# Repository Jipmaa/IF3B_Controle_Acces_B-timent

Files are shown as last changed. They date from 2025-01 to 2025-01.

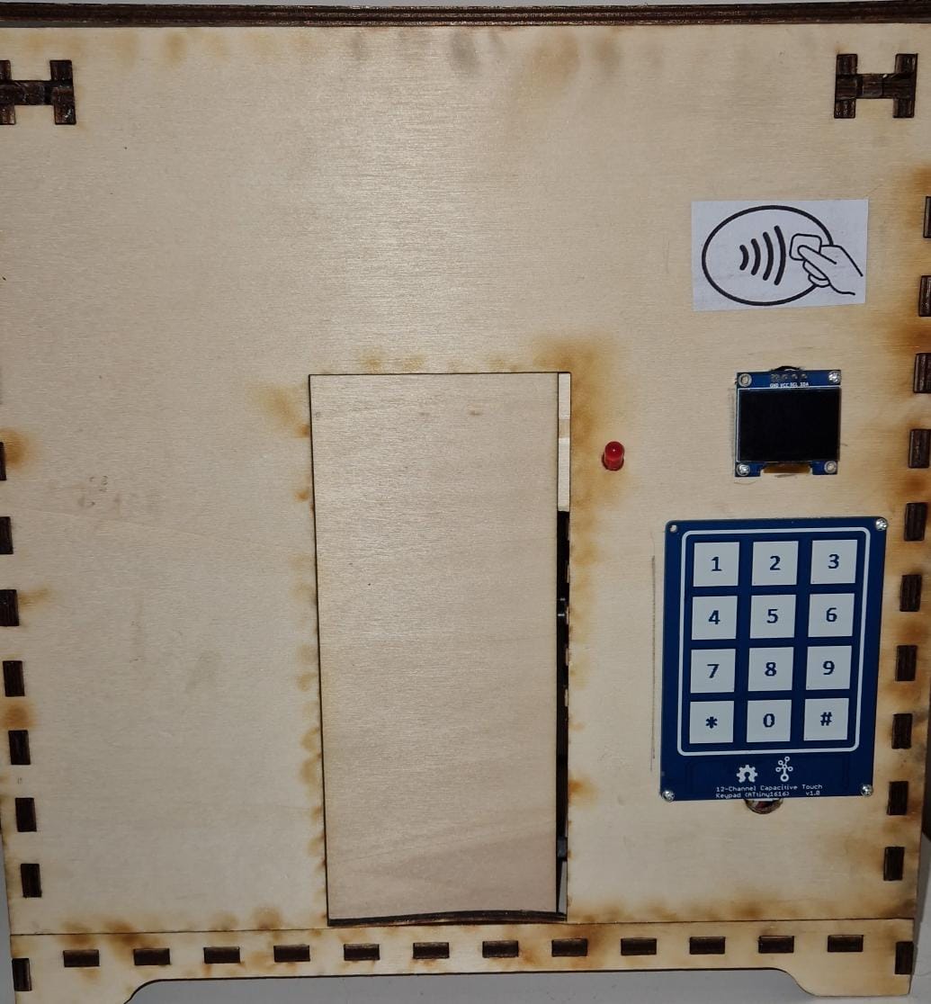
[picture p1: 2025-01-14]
Rendu/Rendu Maquette Face.jpg

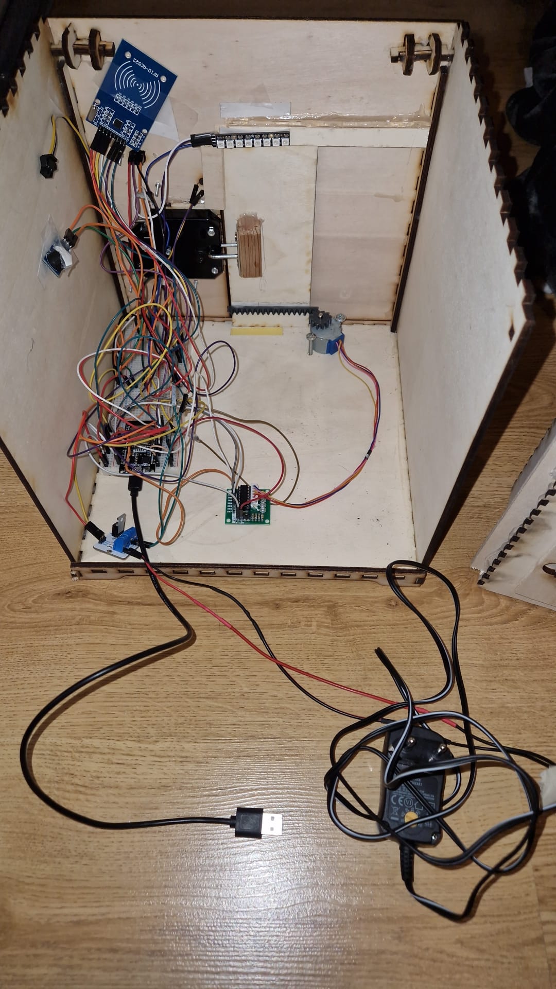
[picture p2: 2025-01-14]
Rendu/Rendu Maquette Interieur Cablage.jpg

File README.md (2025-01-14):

# Projet IF3B
## Contrôle d'accès à un bâtiment

### Contexte :
Dans le cadre des bâtiments modernes, le **contrôle d'accès** représente un enjeu crucial en matière de sécurité, d'efficacité et de gestion des flux de personnes. Les solutions classiques, souvent basées sur des serrures mécaniques ou des systèmes peu intelligents, présentent des limitations : faible flexibilité, difficulté d'intégration avec des systèmes domotiques, et absence de suivi en temps réel.
Pour répondre à ces défis, **notre projet vise à concevoir une solution innovante et interactive de contrôle d'accès pour un bâtiment quelconque**. L'objectif est de développer un système fonctionnel et modulable, intégrant la **communication bidirectionnelle** via Node-RED

### Identification des problèmes :
- Comment faire une porte qui permet d’être verrouillé et qui peut s’ouvrir à distance ?
- Comment indiquer de manière sécurisé qu’une porte va s’ouvrir / se fermer ?
- Comment faire un accès sécurisé et à la fois polyvalent ?
- Comment tracer les entrées des employées par exemple ?

### Solutions proposées :
- Système d’ouverture / fermeture avec porte coulissante modulable via nodered
- Utilisation d’un afficheur OLED, d’un voyant sonore et visuel pour la fermeture et prévenir également avant la fermeture
- Utiliser à la fois un lecteur de badge (module RFID) et un pavé tactile permettant une solution polyvalente
- Permettre l’utilisation d’un badge spécifique ou bien lié un code aux badges quelconques pour déterminer l’entrée d’un employé.

### Répartition des tâches : 
- Conception hardware
- Câblage
- Conception software (capteurs, actionneurs, communication MQTT via wifi)
- Mise en place du serveur NodeRed

### Capteurs / Actionneurs :
- __Module RFID :__ Pour permettre à quiconque possédant un badge valide de rentrer
- __Pavé tactile (keypad) :__ Pour permettre à quiconque possédant le code de rentrer
- __Buzzer :__ Pour indiquer par un bruit toute action fais par l’utilisateur ou bien par le mécanisme susceptible d’être un danger
- __Afficheur OLED :__ Pour indiquer visuellement les instructions à faire ou bien énoncé les erreurs
- __LedStick 8 leds neopixel :__ Pour éclairé l’intérieur, modulable très facilement
- __Moteur stepper :__ moteur pas à pas pour pouvoir faire des rotations sur 360° et ainsi permettre l’utilisation d’un rail et d’un pignon pour ouvrir la porte
- __Serrure à solénoïde :__ serrure permettant d’ouvrir facilement la porte, se ferme en se réenclenchant.

**__Autres :__**
- Résistance
- Led rouge
- Alimentation 12V pour serrure à solénoïde
- Relais pour serrure
- Transformateur pour stepper
- ESP32
- Breadboard

### Détails des pins
**RFID** :
- RST : D4 (modulable)
- MISO : D19
- MOSI : D23
- SCK : D18
- SDA : D5

**Moteur stepper** :
- int1 : D14 (modulable)
- int2 : D27 (modulable)
- int3 : D26 (modulable)
- int4 : D25 (modulable)

**Keypad** :
- RX : RX2
- TX : TX2

**Serrure à solénoïde** :
- SIG : D32 (modulable)

**Afficheur OLED** :
- SCL : D22
- SDA : D21

**LedStick 8 leds neopixel** :
- DIN : D33 (modulable)

**Buzzer** :
- I/O : D13 (modulable)

**Led rouge** :
- D13 (modulable)

**VCC / GND** :
Tous les pins VCC (pour le courant) et GND (pour la masse), sont à brancher sur une breadboard

**__Attention :__** La led ne pourra pas fonctionner correctement, tous les pins jugés "safe" sur l'esp32 sont utilisés, la led s'allumera donc à chaque impulsion électrique envoyé pour faire fonctionner le buzzer

### Câblage
Cablage
(seul la serrure est manquante)

### Rendu final photo
https://github.com/Jipmaa/IF3B_Controle_Acces_Batiment/tree/e7f2aa74cef77e2d99e59e1e05c4c83b59b73495/Rendu

### Rendu final vidéo
Vidéo présentation (https://mega.nz/embed/Z2RXjYpS#6Jan2xSJXGcZ-fgepvT3v_E5NKe26LIGEAMiwmIppC8)

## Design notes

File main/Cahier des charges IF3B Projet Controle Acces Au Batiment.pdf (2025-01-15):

Fabien THUNEVIN – Thomas BALMES – Malak ADAOU – Skander TRABELSI

# Cahier des charges IF3B Projet numéro 5 : Contrôle accès au bâtiment

## Table des matières

## 1. Contexte :

Dans le cadre des bâtiments modernes, le contrôle d'accès représente un enjeu crucial en matière de sécurité, d'efficacité et de gestion des flux de personnes. Les solutions classiques, souvent basées sur des serrures mécaniques ou des systèmes peu intelligents, présentent des limitations : faible flexibilité, difficulté d'intégration avec des systèmes domotiques, et absence de suivi en temps réel.

Pour répondre à ces défis, notre projet vise à concevoir une solution innovante et interactive de contrôle d'accès pour un bâtiment quelconque. L'objectif est de développer un système fonctionnel et modulable, intégrant la communication bidirectionnelle via Node-RED. Durant ce projet nous concevrons une maquette à la découpeuse laser ainsi qu’à l’imprimante 3D pour toute pièce rajoutée, et nous y intégrerons le matériel ARDUINO nécessaire au bon fonctionnement du projet.

## 2. Identification des problèmes

- Comment faire une porte qui permet d’être verrouillé et qui peut s’ouvrir à distance ?
- Comment indiquer de manière sécurisé qu’une porte va s’ouvrir / se fermer ?
- Comment faire un accès sécurisé et à la fois polyvalent ?
- Comment tracer les entrées des employées par exemple ?

## 3. Solutions proposées

- Système d’ouverture / fermeture avec porte coulissante modulable via nodered
- Utilisation d’un afficheur OLED, d’un voyant sonore et visuel pour la fermeture et prévenir également avant la fermeture
- Utiliser à la fois un lecteur de badge (module RFID) et un pavé tactile permettant une solution polyvalente

- Permettre l’utilisation d’un badge spécifique ou bien lié un code aux badges quelconques pour déterminer l’entrée d’un employé.

## 4. Répartition des tâches :

- Conception hardware : Malak ADAOU
- Câblage : Thomas BALMES
- Conception software (capteurs, actionneurs, communication MQTT via wifi) : Fabien THUNEVIN
- Mise en place du serveur NodeRed : Fabien THUNEVIN

La maquette va se présenter de la forme suivante : une maison avec une porte qui sera verrouillé par une serrure reliée à un contrôleur NFC qui s’active / désactive, un servomoteur ouvrira la porte et une led ainsi qu’un panneau OLED nous indiquera si la porte est ouverte ou non. Un détecteur fera en sorte que la porte ne se referme pas de manière abrupte sur une personne essayant de rentrer.

## 5. Capteurs / Actionneurs

- Module RFID : Pour permettre à quiconque possédant un badge valide de rentrer
- Pavé tactile : Pour permettre à quiconque possédant le code de rentrer
- Buzzer : Pour indiquer par un bruit toute action fais par l’utilisateur ou bien par le mécanisme susceptible d’être un danger
- Afficheur OLED : Pour indiquer visuellement les instructions à faire ou bien énoncé les erreurs
- LedStick 8 leds neopixel : Pour éclairer l’intérieur, modulable très facilement
- Moteur stepper : moteur pas à pas pour pouvoir faire des rotations sur 360° et ainsi permettre l’utilisation d’un rail et d’un pignon pour ouvrir la porte
- Serrure à solénoïde : serrure permettant d’ouvrir facilement la porte, se ferme en se réenclenchant.

Autres :

- 1 Led
- 1 Résistance
- 2 breadboards
- Câbles duponts
- 1 Câble micro-usb
- Microcontrôleur esp32
- Transformateur pour moteur stepper
- Relais pour serrure
- Alimentation 12V pour serrure à solenoïde.

## 6. Logigramme

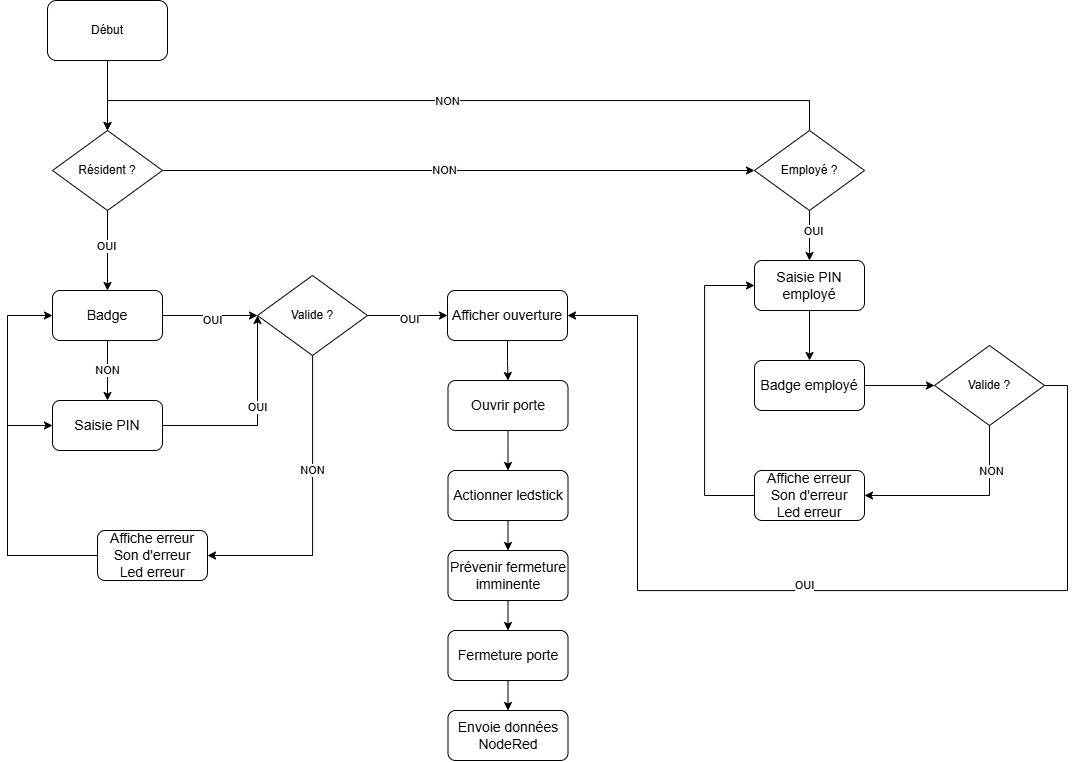
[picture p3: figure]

## 7. Schéma de câblage

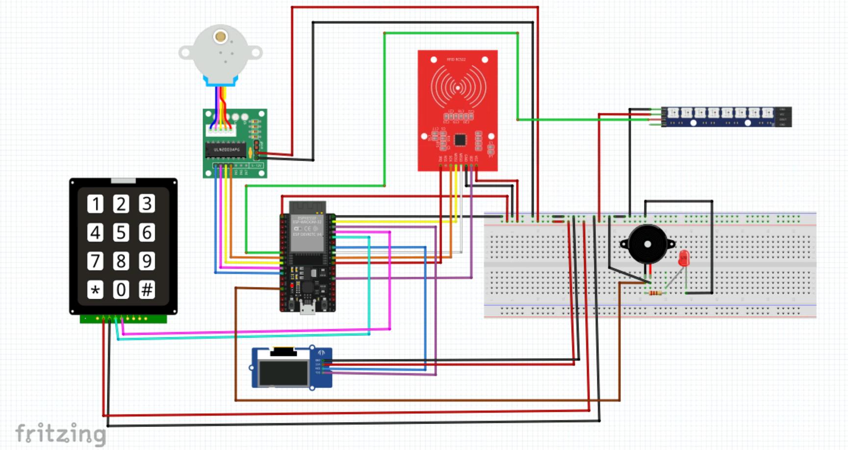
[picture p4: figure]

Ainsi qu’une serrure à solénoïde dont le SIG est branché sur le pin D32.

## 8. Intégration NodeRed

- Permet le contrôle de la porte et de ses 4 états (ouvert, ouverture, fermée, fermeture)
- Permet de contrôler les couleurs du LedStick
- Permet d’afficher le message de son choix sur l’écran OLED avec la taille souhaité tout en le faisant défilé. Également la possibilité de revenir au message initial
- Permet de donner une impulsion au buzzer pour émettre un son de la fréquence et à la durée souhaité

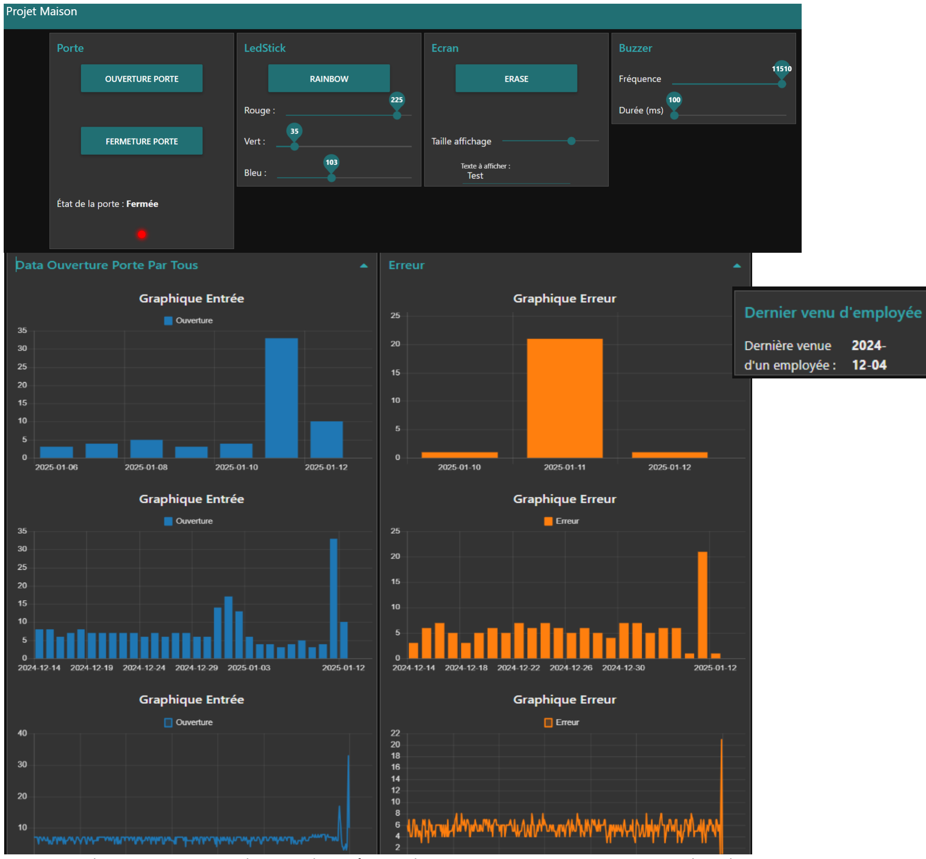
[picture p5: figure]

- Affichage des graphiques d’entrée et d’erreur sur les 7, 30 et 365 derniers jours

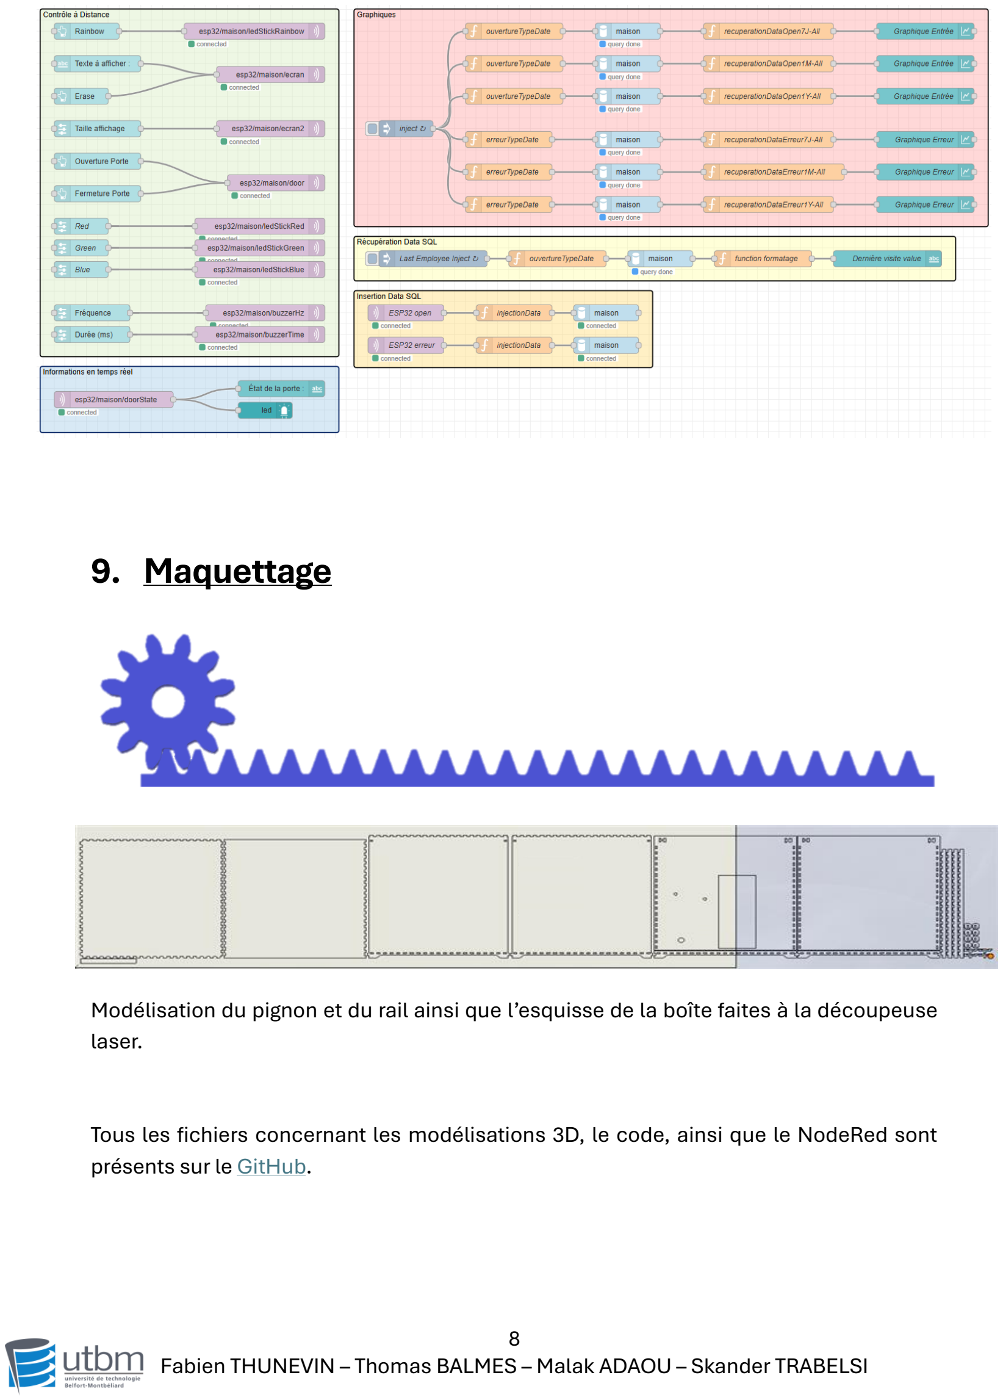
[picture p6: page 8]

## 9. Maquettage

Modélisation du pignon et du rail ainsi que l’esquisse de la boîte faites à la découpeuse laser.

Tous les fichiers concernant les modélisations 3D, le code, ainsi que le NodeRed sont présents sur le GitHub. (https://github.com/Jipmaa/IF3B_Controle_Acces_Batiment/tree/main)

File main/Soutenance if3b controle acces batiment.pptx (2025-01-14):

## Soutenance IF3B

Contrôle d’accès au bâtiment

Fabien THUNEVIN - Thomas BALMES - Malak ADAOU - Skander TRABELSI

## Contexte

- Système connecté
- Sécuriser un accès
- Garder un aspect simple mais efficace

## Identification des problèmes

- Comment ouvrir la porte ?

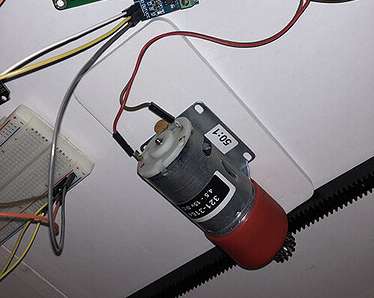
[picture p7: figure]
porte coulissante - Français - Arduino Forum

Image d’internet

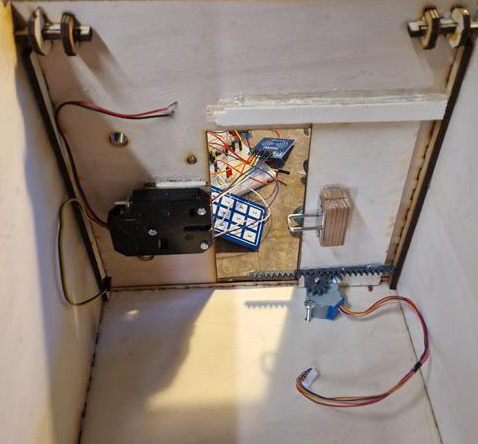
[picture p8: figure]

Image de la maquette

## Problèmes rencontrés

- ?????

## Capteurs / Actionneurs

Capteurs | Actionneurs
RFID | Afficheur OLED
Keypad | Moteur stepper
Buzzer | Serrure à solénoïde

## Répartition des tâches

- Conception hardware : Malak ADAOU
- Câblage : Thomas BALMES
- Conception software (capteurs, actionneurs, communication MQTT via wifi) : Fabien THUNEVIN
- Mise en place du serveur NodeRed : Fabien THUNEVIN

## Conception hardware

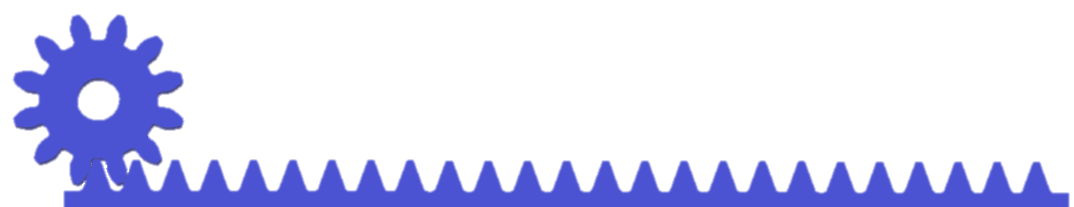
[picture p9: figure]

## Câblage

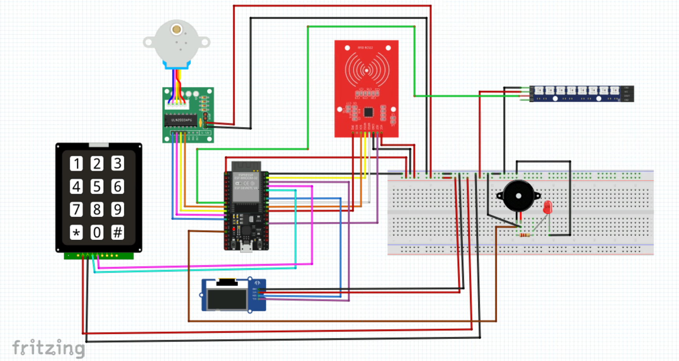
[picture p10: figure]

## Travail de groupe

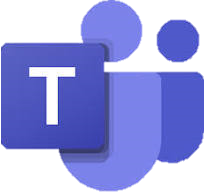
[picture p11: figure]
Microsoft Teams — Wikipédia

## Logigramme

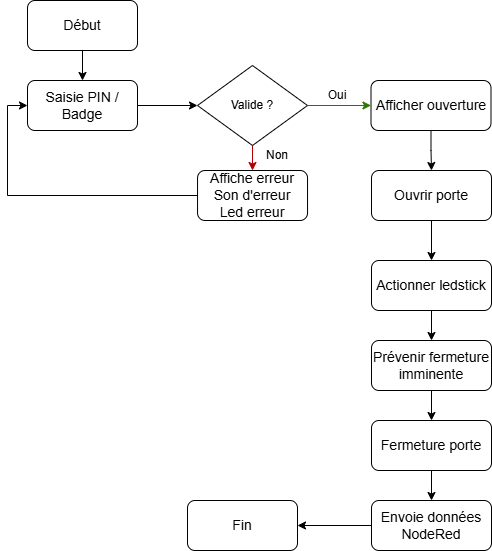
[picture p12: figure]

## Intégration de NodeRed

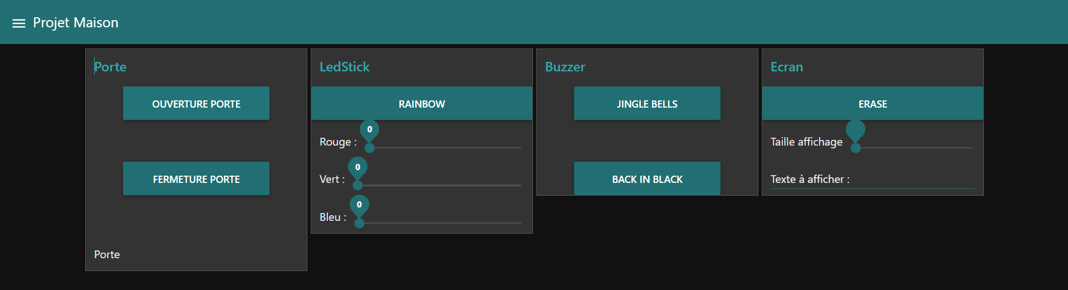
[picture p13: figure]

## Intégration de NodeRed

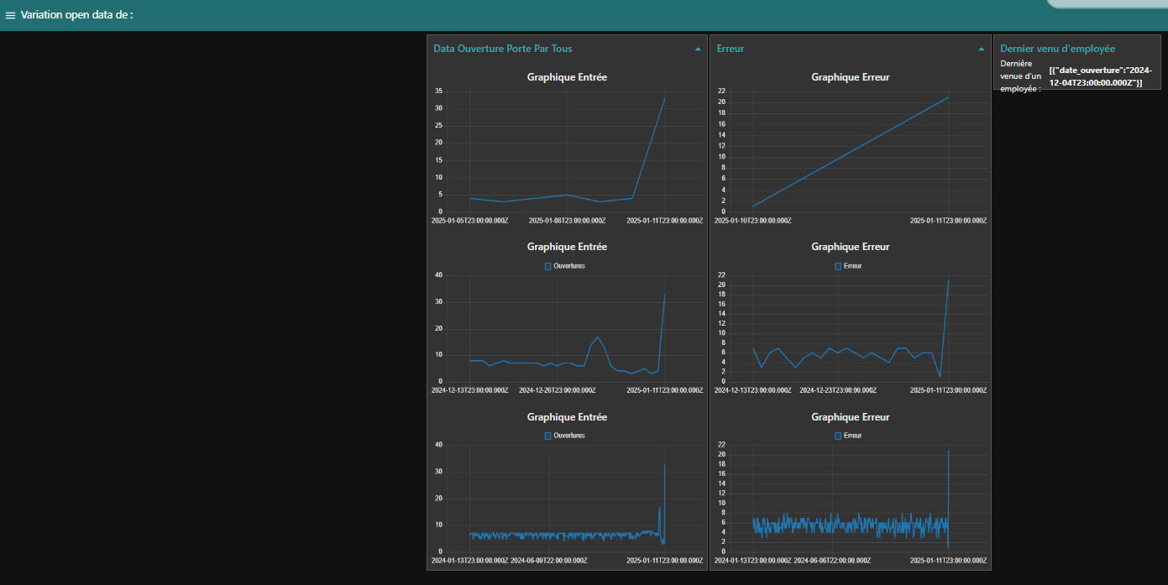
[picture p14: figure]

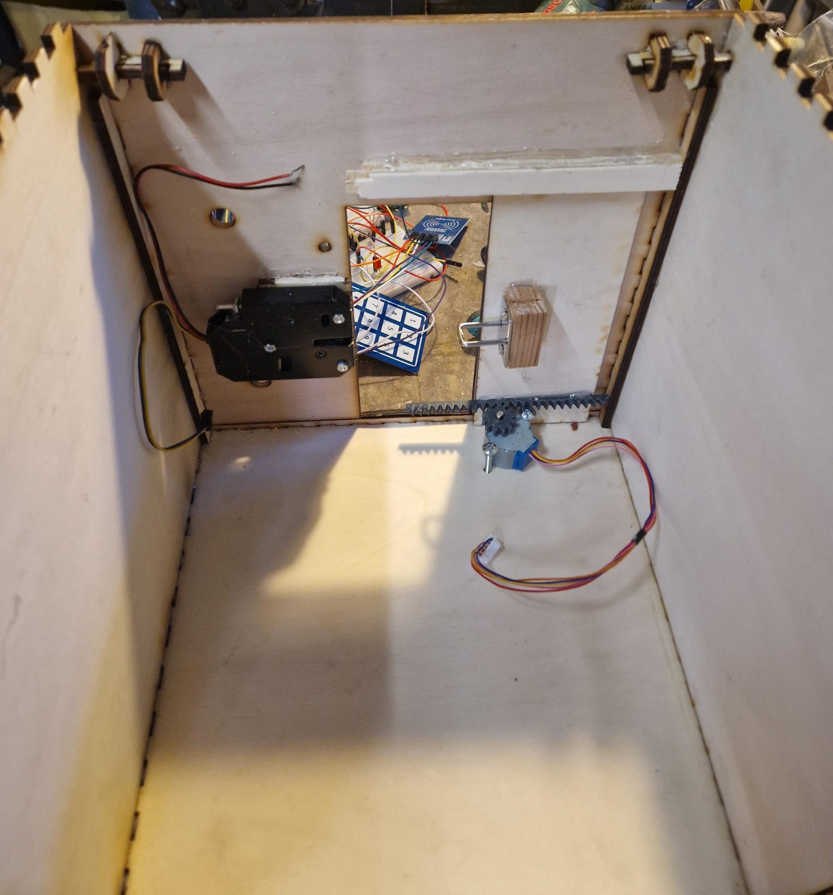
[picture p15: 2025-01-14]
Rendu/Rendu Maquette Interieur Simple.jpg

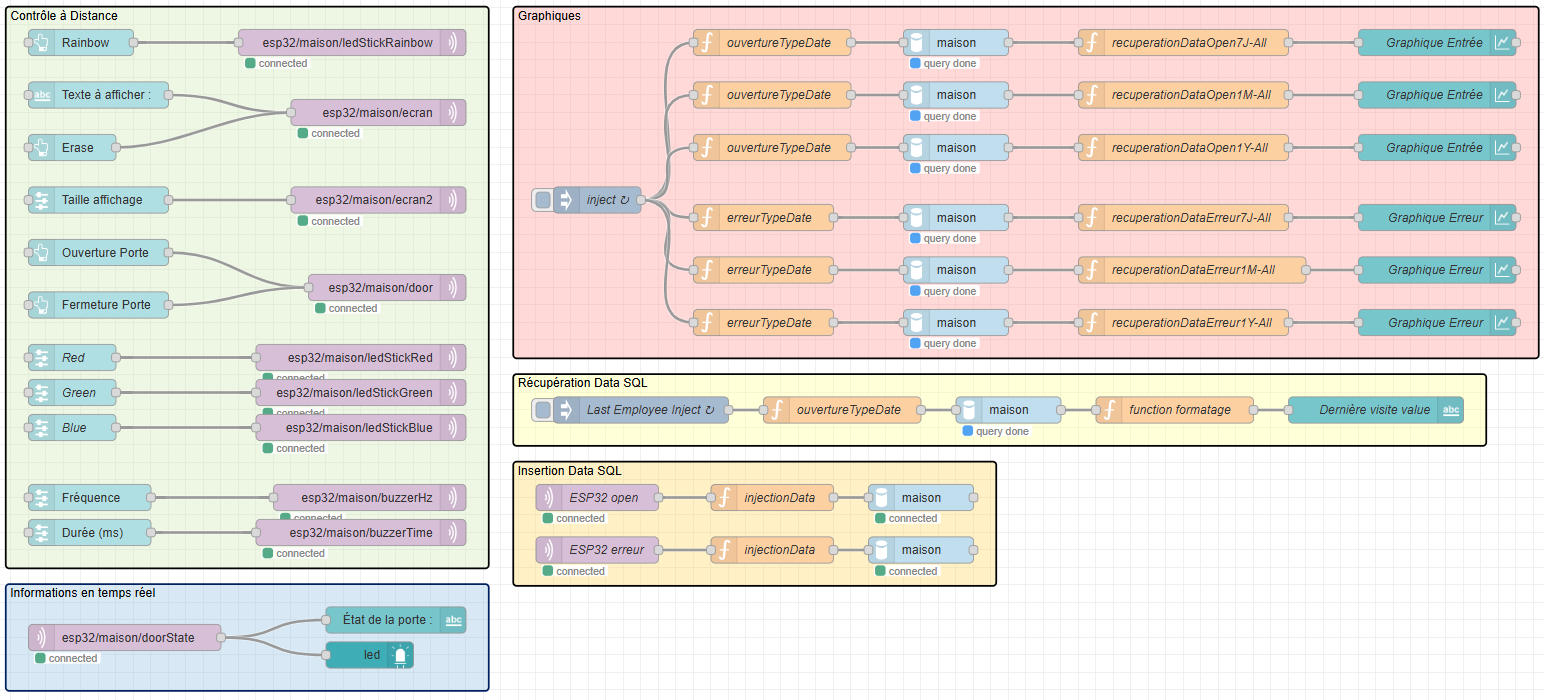
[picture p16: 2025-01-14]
Rendu/Rendu NodeRed.png

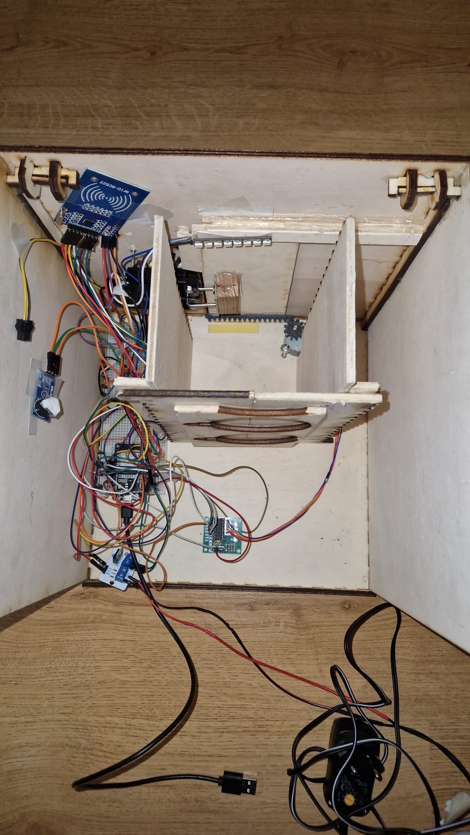
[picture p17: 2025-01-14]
Rendu/Rendu Maquette Vu Dessus.jpg

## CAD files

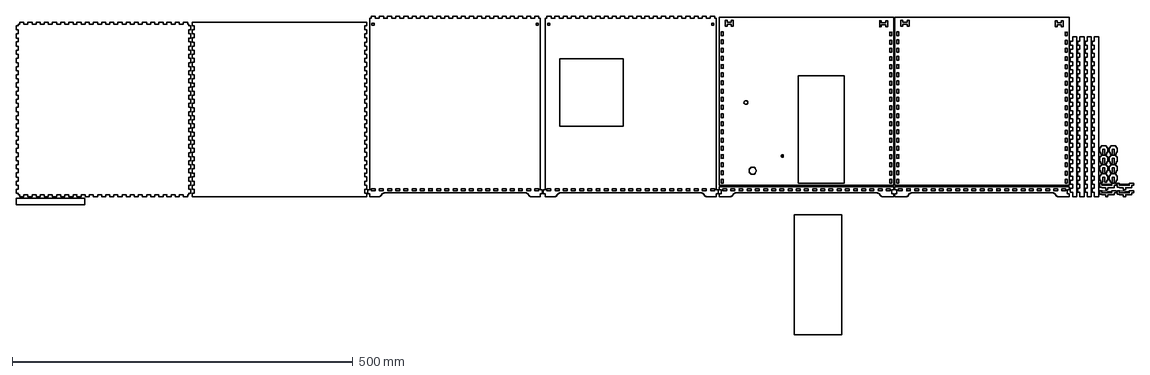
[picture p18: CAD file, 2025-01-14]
Modèles 3D/box maquette decoupeuse laser.dxf
1638.9 x 467.7 mm

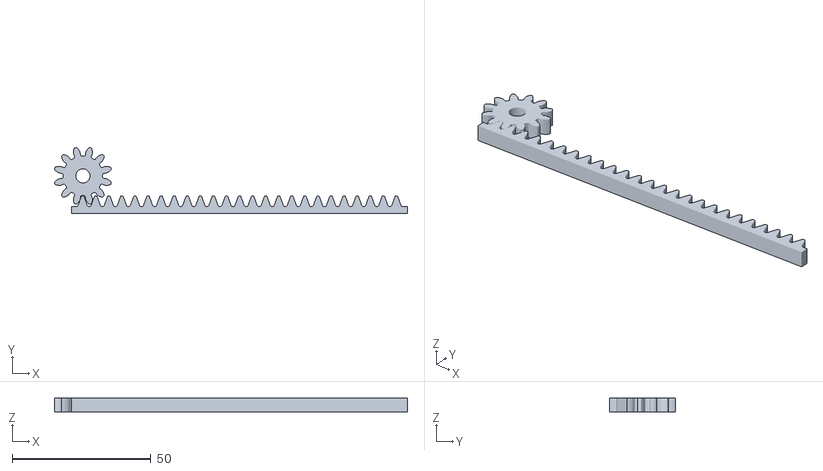
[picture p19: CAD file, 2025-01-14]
Modèles 3D/pignon et rail moteur porte.stl
127.3 x 23.8 x 5.00

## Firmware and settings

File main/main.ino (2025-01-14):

#include <Wire.h>
#include <Adafruit_GFX.h>
#include <Adafruit_SSD1306.h>
#include <SPI.h>
#include <MFRC522.h>
#include <Stepper.h>
#include <Adafruit_NeoPixel.h>
#include <WiFi.h>          // Cette bibliothèque permet à l'ESP32 de se connecter au réseau WiFi.
#include <PubSubClient.h>  // Cette bibliothèque vous permet d'envoyer et de recevoir des messages MQTT.


//Oled
#define SCREEN_WIDTH 128  // OLED display width, in pixels
#define SCREEN_HEIGHT 64  // OLED display height, in pixels
//Keypad
#define RX_PIN 17  // Connecté à TX du keypad
#define TX_PIN 16  // Connecté à RX du keypad
// Declaration for SSD1306 display connected using I2C
#define OLED_RESET -1  // Reset pin
#define SCREEN_ADDRESS 0x3C
//Led Stick
#ifdef __AVR__
#include <avr/power.h>  // Required for 16 MHz Adafruit Trinket
#endif
#define LED_PIN 33 //au lieu de 19
#define LED_COUNT 8
#define RST_PIN 4
#define SS_PIN 5

// "Variables" globales
const int relay = 32;
const int buzzer = 13;
const int ledRed = 33;
const int stepsPerRevolution = 2038;
int red = 255;
int green = 255;
int blue = 255;
String lastMessageOLED = "";
String lastStateDoor = "close";
unsigned int freq_tone = 200;
unsigned long time_tone = 200;

// Declaration for an SSD1306 display connected to I2C (SDA, SCL pins) = oled
Adafruit_SSD1306 display(SCREEN_WIDTH, SCREEN_HEIGHT, &Wire, -1);
// rfid
MFRC522 mfrc522(SS_PIN, RST_PIN);
// Init array that will store new NUID
byte nuidPICC[4];
// Stepper
Stepper myStepper(stepsPerRevolution, 14, 26, 27, 25);
//Keypad
HardwareSerial TRANS_SERIAL(1);  // Utiliser le port UART1
String codeCorrect = "5190";
String codeCorrectEmploye = "1234";
String codeSaisi = "";
//LedStocl
Adafruit_NeoPixel strip(LED_COUNT, LED_PIN, NEO_RGB + NEO_KHZ800);
//Wifi
WiFiClient espClientTHUNE;                 // Initialiser la bibliothèque client wifi (connexion WiFi)
PubSubClient clientTHUNE(espClientTHUNE);  // Créer un objet client MQTT (connexion MQTT)

const char* ssid = "Partage de co";                //Nom du wifi
const char* password = "Tomates08";                //Mot de passe du wifi
const char* mqtt_server = "mqtt.ci-ciad.utbm.fr";  //Nom du serveur
long lastMsg = 0;

void setup() {
  Serial.begin(9600);  // Initialisation du port série
  while (!Serial)
    ;
  delay(100);
  Serial.println("Debug: Début de setup.");

  pinMode(ledRed, OUTPUT);
  pinMode(buzzer, OUTPUT);
  pinMode(relay, OUTPUT);
  digitalWrite(relay, LOW);
  myStepper.setSpeed(8);

  //rfid
  SPI.begin();                        // Init SPI bus
  mfrc522.PCD_Init();                 // Init MFRC522
  delay(100);                         // Optional delay. Some board do need more time after init to be ready, see Readme
  mfrc522.PCD_DumpVersionToSerial();  // Show details of PCD - MFRC522 Card Reader details
  Serial.println(F("Scan PICC to see UID, SAK, type, and data blocks..."));

  // Initialisation de l'écran OLED
  if (!display.begin(SSD1306_SWITCHCAPVCC, SCREEN_ADDRESS)) {
    Serial.println(F("Erreur : OLED non détecté."));
    while (true)
      ;  // Boucle infinie si l'OLED échoue
  }
  affichageScan(0, "a");  // Affichage par défaut

  // Initialisation du clavier
  TRANS_SERIAL.begin(9600, SERIAL_8N1, RX_PIN, TX_PIN);
  Serial.println("Debug: Clavier initialisé.");

  // Initialisation de la bande LED
  strip.begin();
  strip.show();
  strip.setBrightness(50);
  colorWipe(strip.Color(green, red, blue), 10);  // Couleur blanche par défaut


  setup_wifi();
  clientTHUNE.setServer(mqtt_server, 1883);
  clientTHUNE.setCallback(callback);
  Serial.println("Debug: Fin de setup.");
}



void loop() {
  checkingData();
  recupDataKeyboard();
  if (!mfrc522.PICC_IsNewCardPresent()) {
    return;
  }

  if (!mfrc522.PICC_ReadCardSerial()) {
    return;
  }
  Serial.println("Erreur 3333333333333333333333333");
  String UID = "";

  for (byte i = 0; i < mfrc522.uid.size; i++) {
    UID.concat(String(mfrc522.uid.uidByte[i] < 0x10 ? " 0" : " "));
    UID.concat(String(mfrc522.uid.uidByte[i], HEX));
  }

  UID.toUpperCase();

  if (UID.substring(1) == "36 92 8B 44" || ((UID.substring(1) == "8B 7E BD 22" || UID.substring(1) == "BA FC A6 16" || 
  UID.substring(1) == "39 77 91 6D") && codeSaisi == codeCorrectEmploye)) {

    sendData(2);
    affichageScan(1, "Employe\nreconnu");
    delay(2000);
    ouverture();

  } else if (UID.substring(1) == "8B 7E BD 22" || UID.substring(1) == "BA FC A6 16" || UID.substring(1) == "39 77 91 6D") {
    sendData(1);
    ouverture();
  }  else {
    affichageScan(2, "Badge non autorise");
    erreur();
  }
}

void ouverture() {
  codeSaisi = "";
  Serial.println("test beginning condition");

  affichageScan(1, "Ouverture");  //oled

  //https://javl.github.io/image2cpp/?pseSrc=pgEcranOledArduino
  //serrure
  digitalWrite(relay, HIGH);  //serrure "éjecté"

  digitalWrite(ledRed, LOW);

  tone(buzzer, 1000, 200);
  delay(50);
  tone(buzzer, 250, 200);

  //moteur
  Serial.println("Ouverture");
  clientTHUNE.publish("esp32/maison/doorState", "En ouverture");
  myStepper.step(-stepsPerRevolution * 1.2);
  clientTHUNE.publish("esp32/maison/doorState", "Ouverte");
  green = 255;
  red = 0;
  blue = 0;
  for (int i = 0 ; i < 5 ; i++) {
    colorWipe(strip.Color(green, red, blue), 100);
    green = 0;
    red = 255;
    colorWipe(strip.Color(green, red, blue), 100);
    red = 0;
    blue = 255;
    colorWipe(strip.Color(green, red, blue), 100);
    blue = 0;
    green = 255;
    colorWipe(strip.Color(green, red, blue), 100);
  }
  blue = 255;
  red = 255;
  colorWipe(strip.Color(green, red, blue), 10);


  affichageScan(1, "Fermeture imminente");

  for (int j = 0; j < 2; j++) {
    digitalWrite(ledRed, HIGH);
    tone(buzzer, 250, 200);
    delay(500);
    digitalWrite(ledRed, LOW);
    tone(buzzer, 250, 200);
    delay(500);
  }

  digitalWrite(relay, LOW);
  tone(buzzer, 250, 1500);
  affichageScan(1, "Fermeture");

  // 1 rotation counterclockwise:
  Serial.println("Fermeture");
  clientTHUNE.publish("esp32/maison/doorState", "En fermeture");
  myStepper.step(stepsPerRevolution * 1.2);
  clientTHUNE.publish("esp32/maison/doorState", "Fermée");
  delay(1000);

  colorWipe(strip.Color(255, 255, 255), 1);  // White

  affichageScan(0, "a");
}

void erreur() {

  sendData(0);

  tone(buzzer, 1000, 200);
  delay(50);
  tone(buzzer, 250, 1000);

  for (int j = 0; j < 5; j++) {
    digitalWrite(ledRed, HIGH);
    delay(500);
    digitalWrite(ledRed, LOW);
    delay(500);
  }

  tone(buzzer, 250, 200);

  affichageScan(0, "a");
}


// Affiche un message par défaut si x = FALSE
void affichageScan(int x, String msg) {

  if (x == 1) {

    display.clearDisplay();
    display.setTextSize(2);
    display.setTextColor(WHITE);
    display.setCursor(5, 30);

    // Display static text
    display.println(msg);
    display.display();
    display.stopscroll();

  } else if (x == 0) {

    display.clearDisplay();
    display.setTextSize(2);
    display.setTextColor(WHITE);
    display.setCursor(5, 30);

    // Display static text
    display.println("Scan badge");
    display.display();
    display.stopscroll();

  } else if (x == 2) {
    display.clearDisplay();
    display.setTextColor(INVERSE);
    display.setCursor(5, 30);
    display.println(msg);
    display.startscrollleft(0x00, 0x07);
    display.display();
  }
}


// Keypad
void recupDataKeyboard() {
  while (TRANS_SERIAL.available()) {
    uint8_t data = TRANS_SERIAL.read();
    switch (data) {
      case 0xE1:  // "1"
        Serial.println("1");
        ajouterTouche('1');
        tone(buzzer, 750, 200);
        break;
      case 0xE2:  // "2"
        Serial.println("2");
        ajouterTouche('2');
        tone(buzzer, 800, 200);
        break;
      case 0xE3:  // "3"
        Serial.println("3");
        ajouterTouche('3');
        tone(buzzer, 850, 200);
        break;
      case 0xE4:  // "4"
        Serial.println("4");
        ajouterTouche('4');
        tone(buzzer, 900, 200);
        break;
      case 0xE5:  // "5"
        Serial.println("5");
        ajouterTouche('5');
        tone(buzzer, 950, 200);
        break;
      case 0xE6:  // "6"
        Serial.println("6");
        ajouterTouche('6');
        tone(buzzer, 1000, 200);
        break;
      case 0xE7:  // "7"
        Serial.println("7");
        ajouterTouche('7');
        tone(buzzer, 1050, 200);
        break;
      case 0xE8:  // "8"
        Serial.println("8");
        ajouterTouche('8');
        tone(buzzer, 1100, 200);
        break;
      case 0xE9:  // "9"
        Serial.println("9");
        ajouterTouche('9');
        tone(buzzer, 1150, 200);
        break;
      case 0xEA:  // "*"
        Serial.println("*");
        Serial.println("Effacement du code saisi.");
        tone(buzzer, 1200, 200);
        affichageScan(0, "a");
        digitalWrite(ledRed, HIGH);
        delay(500);
        digitalWrite(ledRed, LOW);
        codeSaisi = "";  // Réinitialise le code
        break;
      case 0xEB:  // "0"
        Serial.println("0");
        ajouterTouche('0');
        tone(buzzer, 1250, 200);
        break;
      case 0xEC:  // "#"
        Serial.println("#");
        tone(buzzer, 1300, 200);
        verifierCode();  // Vérifie le code saisi
        break;
      default:
        Serial.println("Touche inconnue.");
    }
  }
}


void ajouterTouche(char touche) {
  codeSaisi += touche;  // Ajoute la touche au code saisi
  affichageCode();
}


void verifierCode() {
  Serial.println("Code entré : ");
  Serial.print(codeSaisi);

  if (codeSaisi == codeCorrect) {

    Serial.println("Code correct ! Ouverture...");
    affichageScan(1, "Code bon");
    delay(500);
    sendData(1);
    ouverture();

  } else {

    Serial.println("Code incorrect ! Accès refusé.");
    affichageScan(1, "Code\nincorrect");
    erreur();
    delay(500);
  }
}



void affichageCode() {

  Serial.print("Longueur du code : ");
  Serial.println(codeSaisi.length());
  Serial.print("Code saisi : ");
  Serial.println(codeSaisi);

  if (codeSaisi.length() < 5) {  // à remettre 5 ici

    display.clearDisplay();
    display.setTextSize(2);
    display.setTextColor(WHITE);
    display.setCursor(25, 30);

    for (int i = 0; i < codeSaisi.length(); i++) {
      
      display.print("*");
    }

    display.display();
  }

  else {
    affichageScan(1, "Code\nincorrect");
    codeSaisi = "";
    erreur();
  }
}



// Rainbow cycle along whole strip. Pass delay time (in ms) between frames.
void rainbow(int wait) {
  green = 255;
  red = 0;
  blue = 0;
  for (int i = 0 ; i < 5 ; i++) {
    colorWipe(strip.Color(green, red, blue), 100);
    green = 0;
    red = 255;
    colorWipe(strip.Color(green, red, blue), 100);
    red = 0;
    blue = 255;
    colorWipe(strip.Color(green, red, blue), 100);
    blue = 0;
    green = 255;
  }
  red = 255;
  blue = 255;
  colorWipe(strip.Color(green, red, blue), 10);
}


void colorWipe(uint32_t color, int wait) {
  for (int i = 0; i < strip.numPixels(); i++) {  // For each pixel in strip...
    strip.setPixelColor(i, color);               //  Set pixel's color (in RAM)
    strip.show();                                //  Update strip to match
    delay(wait);                                 //  Pause for a moment
  }
}



void setup_wifi() {
  delay(10);
  Serial.println();
  Serial.print("Connecting to ");
  Serial.println(ssid);

  WiFi.begin(ssid, password);

  while (WiFi.status() != WL_CONNECTED) {
    delay(500);
    Serial.print(".");
  }

  Serial.println("");
  Serial.println("WiFi connected");
  Serial.println("IP address: ");
  Serial.println(WiFi.localIP());
}


// Application des requêtes MQTT reçues via nodered
void callback(char* topic, byte* message, unsigned int length) {
  Serial.print("Message arrived on topic: ");
  Serial.print(topic);
  Serial.println(". Message: ");
  String messageTemp;

  for (int i = 0; i < length; i++) {
    Serial.print((char)message[i]);
    messageTemp += (char)message[i];
  }
  Serial.println();

  if (String(topic) == "esp32/maison/door") {
    if (messageTemp == "onDoor") {  
    clientTHUNE.publish("esp32/maison/doorState", "En ouverture");
      digitalWrite(relay, HIGH);  //serrure "éjecté"
      myStepper.step(-stepsPerRevolution * 1.2);  // Ouvrir la porte
      digitalWrite(relay, LOW); 
      clientTHUNE.publish("esp32/maison/doorState", "Ouverte");
      Serial.println("Porte ouverte !");
    } else if (messageTemp == "offDoor") {
      clientTHUNE.publish("esp32/maison/doorState", "En fermeture");
      myStepper.step(stepsPerRevolution * 1.2);  // Fermer la porte
      clientTHUNE.publish("esp32/maison/doorState", "Fermée");
      Serial.println("Porte fermee !");
    } else {
      Serial.println("Problème messageTemp pour Moteur");
    }
  }


  if (String(topic) == "esp32/maison/ledRed") {
    if (messageTemp == "onLed") {
      digitalWrite(ledRed, HIGH);
    } else if (messageTemp == "offLed") {
      digitalWrite(ledRed, LOW);
    } else {
      Serial.println("Problème messageTemp pour LedRed");
    }
  }

  if (String(topic) == "esp32/maison/buzzerHz") {
    freq_tone = (unsigned int)messageTemp.toInt();
    tone(buzzer, freq_tone, time_tone);
  }

  if (String(topic) == "esp32/maison/buzzerTime") {
    time_tone = (unsigned long)messageTemp.toInt();
    tone(buzzer, freq_tone, time_tone);
  }

  if (String(topic) == "esp32/maison/ledStickRed") {
    red = messageTemp.toInt();
    colorWipe(strip.Color(green, red, blue), 100);
  }

  if (String(topic) == "esp32/maison/ledStickGreen") {
    green = messageTemp.toInt();
    colorWipe(strip.Color(green, red, blue), 100);
  }

  if (String(topic) == "esp32/maison/ledStickBlue") {
    blue = messageTemp.toInt();
    colorWipe(strip.Color(green, red, blue), 100);
  }

  if (String(topic) == "esp32/maison/ledStickRainbow") {
    rainbow(10);
  }

  if (String(topic) == "esp32/maison/ecran2") {
    display.setTextSize(messageTemp.toInt());
    affichageScan(2, lastMessageOLED);
    Serial.println("Changement taille texte");
  }
  if (String(topic) == "esp32/maison/ecran") {
    if (messageTemp == "EraseAll") {
      affichageScan(0, "a");
      lastMessageOLED = "Scan badge";
    } else {
      affichageScan(2, messageTemp);
      lastMessageOLED = messageTemp;
    }
  }
}



//La fonction "reconnect()" est utilisée pour garantir la connexion MQTT entre l'ESP32 et le broker MQTT.
//Elle est appelée dans la boucle principale et elle se répète jusqu'à ce que la connexion soit établie avec succès.
void reconnect() {
  while (!clientTHUNE.connected()) {
    Serial.print("Attempting MQTT connection...");
    if (clientTHUNE.connect("espClientTHUNE")) {
      Serial.println("connected");
      // Subscribe
      clientTHUNE.subscribe("esp32/maison/ledRed");
      clientTHUNE.subscribe("esp32/maison/buzzerHz");
      clientTHUNE.subscribe("esp32/maison/buzzerTime");
      clientTHUNE.subscribe("esp32/maison/door");
      clientTHUNE.subscribe("esp32/maison/ledStickRed");
      clientTHUNE.subscribe("esp32/maison/ledStickBlue");
      clientTHUNE.subscribe("esp32/maison/ledStickGreen");
      clientTHUNE.subscribe("esp32/maison/ledStickRainbow");
      clientTHUNE.subscribe("esp32/maison/ecran");
      clientTHUNE.subscribe("esp32/maison/ecran2");
    } else {
      Serial.print("failed, rc=");
      Serial.print(clientTHUNE.state());
      Serial.println(" try again in 5 seconds");
      delay(5000);
    }
  }
}


int lastLedState = 0;


void checkingData() {
  if (!clientTHUNE.connected()) {
    reconnect();
  }
  clientTHUNE.loop();
  long now = millis();
  if (now - lastMsg > 500) {
    lastMsg = now;

    int ledRedState = digitalRead(ledRed);

    if (ledRedState != lastLedState) {
      if (ledRedState == LOW) {
        clientTHUNE.publish("esp32/maison/ledRedDisplay", "off");
        Serial.println("Led OFF");
      } else {
        clientTHUNE.publish("esp32/maison/ledRedDisplay", "on");
        Serial.println("Led ON");
      }
      lastLedState = ledRedState;
    }

    if (lastStateDoor == "open") {
      clientTHUNE.publish("esp32/maison/doorState", "Ouverte");
      lastStateDoor = "null";
    } else if (lastStateDoor == "close") {
      clientTHUNE.publish("esp32/maison/doorState", "Fermée");
      lastStateDoor = "null";
    }
  }
}

//Pour envoyer les données dans la base SQL

void sendData(int identifiant) {

  if (identifiant == 1) {
    Serial.println("Données envoyés OPEN");
    clientTHUNE.publish("esp32/maison/ouverture", "1");
  } else if (identifiant == 2) {
    Serial.println("Données envoyés OPEN");
    clientTHUNE.publish("esp32/maison/ouverture", "2");
  } else if (identifiant == 0) {
    clientTHUNE.publish("esp32/maison/erreur", "null");
    Serial.println("Données envoyés ERREUR");
  } else {
    Serial.println("Problème dans l'identifiant entré");
  }
}
